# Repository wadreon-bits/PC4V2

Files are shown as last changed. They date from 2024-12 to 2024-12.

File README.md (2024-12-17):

# PC4V2  Proto Controller 4volt 2 Channel (Another Stupid Acronym) 

Prototype test platform- Code application and devkit based hardware.
DC Motor controller with Display UI, Aimed to test small ~4volt ERM motors. 2 motor output channels.
Capable of providing 10bit waveform on 2 motor drive h-bridge channels at 100Hz update rate. 

Repository Directory: (protocontrol_4V2)
- ArrayBuilding_Excel 	- Method to build waveforms with excel. Ask for demo.
- Control_Enclosure_R1 	- MCADD files for device enclosure
- PC4V2_Prog1		- Arduino Sketch Folder
- ProtoCheatSheet.doc	- Quick Device instructions
- README.md		- .GIT repo readme doc

Using The Assembled Device:
1. Charge for approx 1hour if discharged -uUSB. Fully charged should read around 4.15vdc or more when device unplugged. 
2. Press either button to wake device
3. Press UP/DWN to select mode#(User setting? Level? Idk)
4. Set to mode#0 to turn device off- will resume sleep in a few seconds.
5. As shipped-The modes are programmed as follows
	- #1-3 are constant speed, 50%, 75%, 100%(motors a/b opp directions)
	- #4-10 are various on/off, and sweeping patterns. Easy to mod. 
	- Can read mode_arrays.h within the code to get a better idea of the patterns programmed. Easy to mod.
6. Alternative hidden mode- Press and hold both buttons simultaneously for >1sec to enter/leave the direct motor drive mode.
	- Use Up/Dwn buttons to set the desired %power to both motor channels. 0%=OFF 100%=ON   
	- NOTE! Most ERM motors will NOT start spinning until >15-20% power is applied. Mode starts at 0.0%.
	- It will stay awake in this mode. Press both btns >1sec again to return to user mode.

Setting Up Arduino IDE: (Updated after R2.2 - after RyanR first load)
1. Download latest IDE from Arduino. Built using (version 2.3.3)
2. In order to add Adafruit framework- perform following
 - File>>Preferences  towards bttm-
 - Copy the following link into 'Additional boards managers URLs:
 - https://adafruit.github.io/arduino-board-index/package_adafruit_index.json
3. IDE Left pane >> BOARDS MANAGER>> Search for Adafruit SAMD
 - Install the SAMD package that includes the FeatherM0 Express
4. Using IDE library Manager - Search for & Install the following libraries
	- Adafruit_NeoPixel
	- Adafruit_SSD1306
	- Adafruit_GFX
	- ArduinoLowPower
6. Lastly - Move the 'PC4V2_Prog1' folder into your Arduino Sketch folder--> Documents>Arduino. 
 - Depending on windows setup- Documents might be a few places - Check onedrive
 - Can check in IDE-  File>>Preferences>>Sketchbook Location: 
7. Tool chain is setup and ready to use. Can edit, compile, and flash devices 

Programming Device:
1. Plug into PC USB port
2. Open Arduino IDE
3. Tools>>Boards  - Select Adafruit Feather M0 Express
4. With a Tack or Paperclip-  Double click the pinhole button on the front button face- proto_UIcontrol. 
5. After the double-click, the feather should re-mount as a new USB com-port. 
	- Helpful note- The Board LED will slowly pulse Red when in proper bootloader mode. Board LED Can been seen right next to feather USB port. 
6. Tools>>Port  - Select the port that now shows (Adafruit Feather M0 Express (SAMD21)).
7. Sketch>>Upload.  The IDE will begin compiling, then begin flash programming the device. 
8. Programming should complete with no warnings or errors. 

The Hardware consists of the following:
1. Feather M0 Express w/Stacking headers
2. Feather OLED 128x32 with standard male header
3. 350mAH lipo - Adafruit- Fits between stacked feather boards. 
4. DRV8833 TI Drive Breakout
5. 3d Printed housing - Onshape: Proto_UIcontrol>>Enclosure4V2
6. See code for pinouts 
7. (Not Used)BS84 P-Chan Mosfet- OLED Pwr Switch
8. (Not USed)0402 15-20k ohm resistor (Pull up for pchannel)

Firmware Notes:
1. Firmware application built original in AS7 at LDC- modified to use Arduino framework
for this version. Based on PC4V1. Now named PC4V2
2. Git Repo will hold updated firmware application files. Along with support docs and support tools.
3. This is DEMO firmware only. No attempts to optimize have been made. All open source. 

FW Functional Description:
1. This application bascially updates a 10bit PWM value every 10milliseconds
   for two h-brige motor outputs. These values come from pre-defined arrays in mode_arrays.h
2. The app scans for valid button presses, and update the current mode_variables
3. If new information is avaialable- an update is made to the OLED 

Modifying Motor Waveform Patterns: 
Adjustments to ERM output patterns will be made within mode_arrays.h
This file can easily be modified for any waveform of interest.
Code must be re-compiled after changes are mode.  

Each mode has 2 arrays, 1 for each motor channel A/B.  

These simple integer arrays hold 10bit PWM duty cycle values.
These values are processed at 100Hz. Array can be length 1 to MANY! Limited by prog flash space.
Values can be between 0(motor off), and 1023(Motor full pwer). Negative Values reverse motor
direction. DO NOT QUICKLY REVERSE MOTOR DIRECTION WITHOUT SLOWING TO A STOP FIRST. 
 
REVERSE DIR	OFF	FORWARD DIR
  -1023		0	1023

const int ExampArrayA[] = {1023} 		//Motor A forward dir 100% power
const int ExampArrayB[] = {0, -511, 0, -511}	//Motor B reverse dir staccato 50% power

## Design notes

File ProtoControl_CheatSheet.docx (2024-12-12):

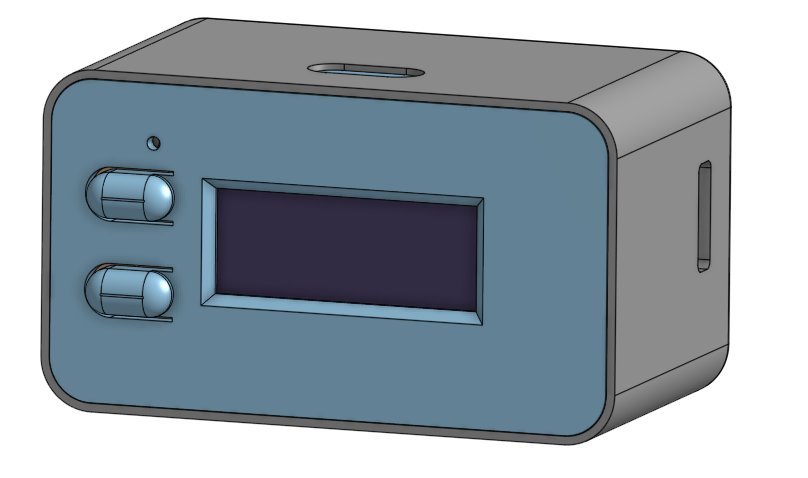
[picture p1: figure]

Screw-Post to Connect

2 Motors

UP+DOWN Buttons

uUSB Charging Port

OLED Display

Charging:

1. Use standard micro-USB cable to charge battery. Charging will take approx. 1hour.
2. Battery icon will read full- and the pack voltage should be around ~4.15Vdc when charged

How To Use:

1. Press ANY button to wake device up
2. Press Up/Dwn Button to set to desired mode #1-10
3. Set to Mode #0 to turn off device. Will resume sleep in a few seconds

How To Modify Motor Waveforms OR Reprogram Device – See Github repo readme

https://github.com/wadreon-bits/ProtoControl_4V2

How To Wire Motors

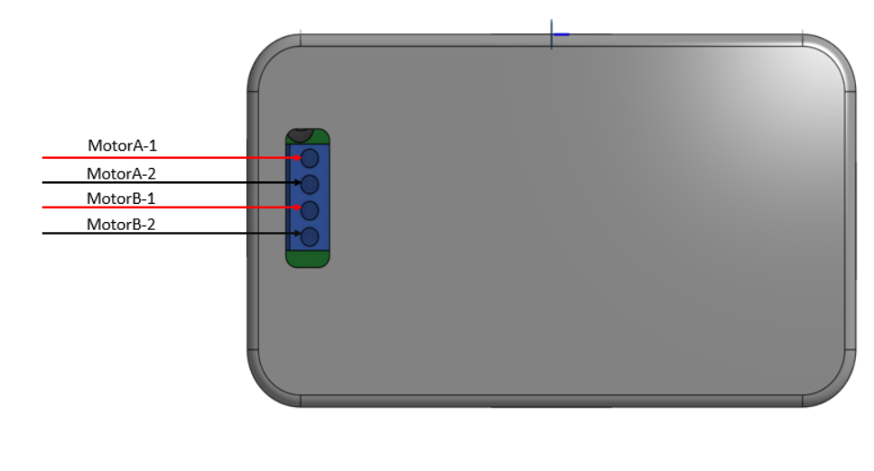
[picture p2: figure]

Proto Controller 4volt 2 Channel 120524

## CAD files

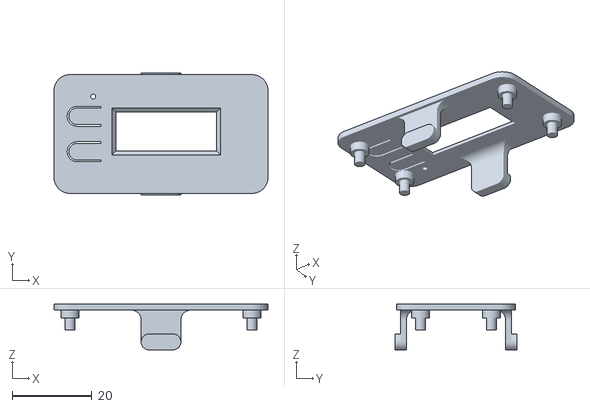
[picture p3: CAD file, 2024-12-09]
Control_Enclosure_R10/Enclosure4V2_R10 - Front.stl
53.8 x 30.6 x 11.5

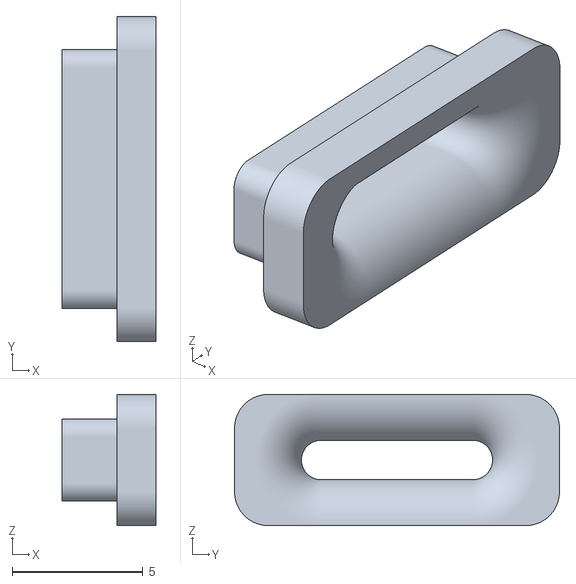
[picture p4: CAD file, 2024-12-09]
Control_Enclosure_R10/Enclosure4V2_R10 - Strain_Relief.stl
3.60 x 12.4 x 5.01

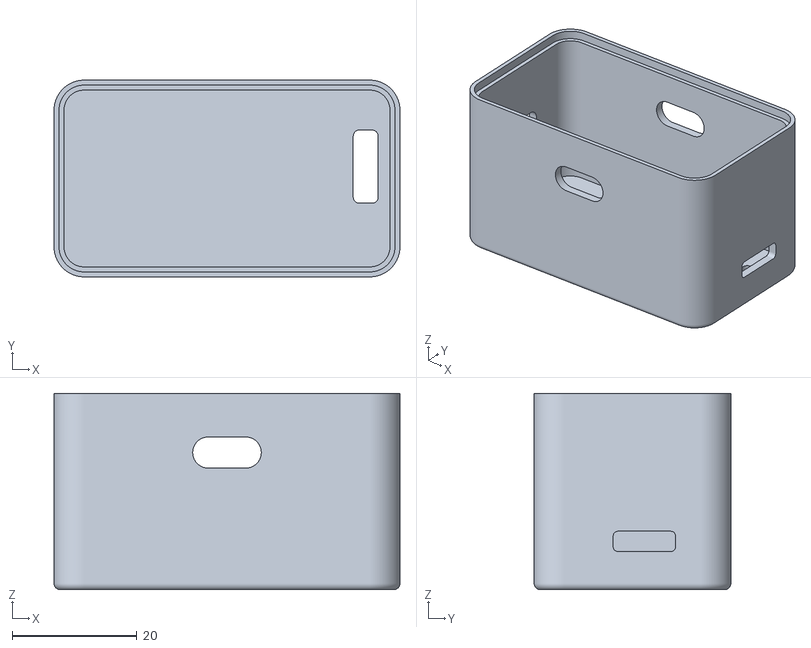
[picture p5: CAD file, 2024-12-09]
Control_Enclosure_R10/Enclosure4V2_R10 - Back.stl
55.5 x 31.6 x 31.5

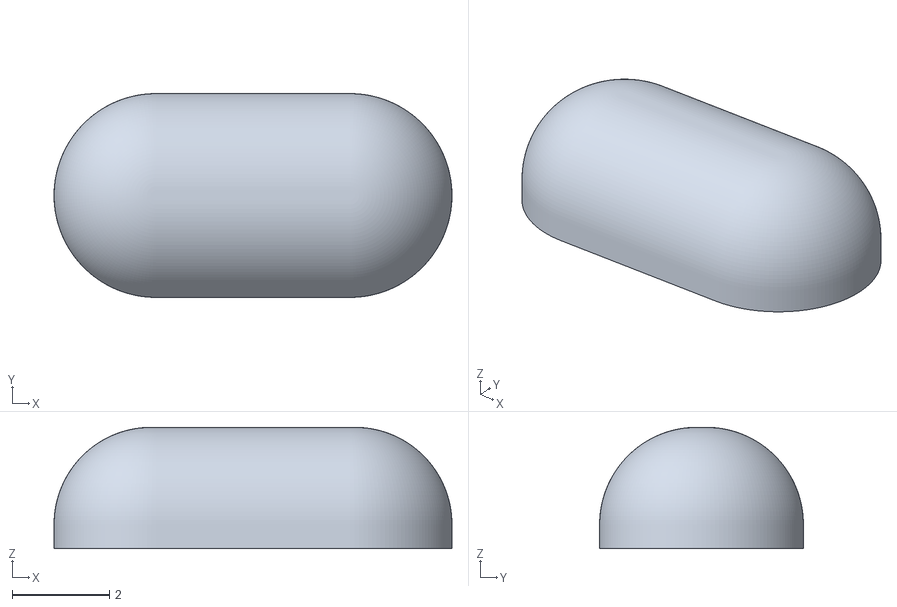
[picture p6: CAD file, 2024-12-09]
Control_Enclosure_R10/Enclosure4V2_R10 - Btn_Oval.stl
8.20 x 4.20 x 2.50

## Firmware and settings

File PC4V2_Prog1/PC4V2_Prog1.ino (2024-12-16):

/*
111824
PC4v2 - MotorTester1S 
Proto Control 4Volts Dual HBridge 2 channel output

FW Versions: See Repo for version history
1.0		111824		Working rebuild of PC4V1 built for LDC. Refactored code for Arduino Framework. Sequences array pwm data to 2 H-bridge channels. 

Arduino Setup Notes: 
See pc4v_support.h for all the libraries needed. Must follow adafruit instructions on installing their libraries. Such as GFX etc.
- Adafruit libraries are all located on a github repo. New version of arduino IDE can search and install adafruit libs natively.
- So if using >=Arduino Version 2.3.3, No need to add link for the adafruit git repo's. 
Sketch >> Include Library >> Library Manager >> Manage Libraries >> Search for library 

HARDWARE NOTES:
Devkit Based Hardware- 
FeatherM0Express
FeatherOLED
DRV8833 Breakout

SOME BUTTON DEFINITIONS - REMOVE NO LONGER NEEDED FOR BASIC UI 
UP - Generic Up index for UI
DWN - Generic Dwn index for UI

Primary Functions to Adjust for Product Interface -
	- app_update()    App Timing			      Manages	primary application timing/time slicing. Basic app. 
	- btn_scan()      BTN UI/Ergonomics			Manages Button ergo- press timing, clicks, etc. Removed clicks for ERM PC4V2
	- mode_manager()	Functional Modes		  Manages enabling motor/led modes and handling periodic mode events. Processes mode_arrays!
  - disp_manager()  OLED Interface        Single function to write/read from OLED display. 
	
Notes-
Arduino makes code writing FAST!!! I hate the IDE- USE AS7 or VScode 
*/
//##############################################################
//  Preamble Include definitions
//##############################################################

#include "pc4v_support.h"

//##############################################################
//  FUNCTION PROTOTYPES
//##############################################################
/*
// Proper .C - populate Function proto's. For compiling with standard C compiler 
// DELETED - ARDUINO FRAMEWORK DOE SALL THIS
*/
#if SOFTWARE_SERIAL_AVAILABLE
  #include <SoftwareSerial.h>
#endif
//End of Auto generated function prototypes by Atmel Studio

/*MACROS*/  
#define WIRE Wire 
#define arrayLen(x) sizeof(x)/sizeof(x[0])  //custom macro for sizing motor/led arrays. 
//#define arrayLen(x) sizeof(x)/sizeof(x[0])  //custom macro for sizing motor/led arrays. 

/*GLOBAL APP EVENT FLAGS*/ 
volatile bool flag_scanBtns   = false;    //flag
volatile bool flag_10ms       = false;    //flag
volatile bool flag_100ms      = false;    //flag
volatile bool flag_1second    = false;    //flag

volatile bool flag_flickerLED = false;    //event
volatile bool flag_gotoSleep  = false;    //event
volatile bool flag_wake_init  = false;    //flag
volatile bool flag_crit_batt  = false;    //flag
volatile bool flag_low_batt   = false;    //event
volatile bool flag_updateDisp = false;    //event

//volatile bool uiflag_fastRate = true; 
volatile bool flag_blockSleep = false;    //set to true to disable sleep 
volatile bool disp_changed    = false; 
bool written_once             = false;


/*Global variables*/
volatile unsigned int btns_state  = 0;	// read - stores pins states
volatile unsigned int btns_cnt    = 0;	// stores pins states
unsigned int btns_stateLast       = 0;		// last pin states


volatile signed int drive_state   = 0;	// Read - Current output duty of drive. 
volatile signed int req_mode      = 0;	// 
volatile signed int active_mode   = 99;	// MODE = USER SETTING or USER LEVEL
volatile signed int aux_pwm       = 0; 
unsigned int led_on               = 0;				// counter to turn off led
unsigned int sleep_counter        = 0;         //
int timer_id                      = 0; 
unsigned int bod33_cnt            = 0; 

int temp_32; 

float batt_volts;
float avg_batt_volts = 4.0; 
String batt_soc; 
//dispState_e disp_state = BOOT; 
enum appState_e app_state = BOOT; 

/* Instantiate Class Object Variables */
Timer app_timer;
Adafruit_NeoPixel serled(1, SER_LED, NEO_GRB + NEO_KHZ800);
#ifdef OLED_CONNECTED
  //Adafruit_SSD1306 display = Adafruit_SSD1306();
  Adafruit_SSD1306 display = Adafruit_SSD1306(128, 32, &WIRE);
#endif


// Synch AC
static __inline__ void ACsync() __attribute__((always_inline, unused));
static void   ACsync() {
	while (AC->STATUSB.bit.SYNCBUSY == 1);
}
// Synch GCLK
static __inline__ void syncADC() __attribute__((always_inline, unused));
static void syncGCLK() {
	while (GCLK->STATUS.bit.SYNCBUSY == 1);
}

//this will be called when the BOD33 threshold is crossed
//once the controller comes out of reset (VAnna rises above threshold)
// so when the battery gets toward BOD33, it will begin interuppting the
//void PM_Handler(){
		//
//}
void SYSCTRL_Handler(){   //BROWN OUT DETECTED 
	int temp_32;

	SYSCTRL->INTFLAG.bit.BOD33DET = 0x1; // clear flag to re-arm interrupt
	SYSCTRL->INTENCLR.bit.BOD33DET = 0x1; //disable interrupt
	//serled.setPixelColor(0, serled.Color(150, 0, 0));
	//serled.show();
	REG_SYSCTRL_INTFLAG |= 0x00000400;  //clear the interrupt flag
	flag_crit_batt = true;
}

/*Power Manager interupt support routine - Not being used*/
//void PM_handler(void){
	//if(REG_PM_RCAUSE == 0x04){ //Brown Out Detected-- Goto Sleep
		//app_timer.stop(timer_id);
	//}
//}

// the setup function runs once when you press reset or power the board
void setup() {
  /* Disable the brown-out detector during configuration,
    otherwise it might misbehave and reset the
    microcontroller. */
  SYSCTRL->BOD33.bit.ENABLE = 0;
  while (!SYSCTRL->PCLKSR.bit.B33SRDY) {};  //wait for sync

  /* Configure the brown-out detector so that the
    program can use it to watch the power supply
    voltage */
  SYSCTRL->BOD33.reg = (
  /* This sets the minimum voltage level to 3.0v - 3.2v.
      See datasheet table 37-21. */
  SYSCTRL_BOD33_LEVEL(48) |
  /* Since the program is waiting for the voltage to rise,
      don't reset the microcontroller if the voltage is too
      low. */
  SYSCTRL_BOD33_ACTION_INTERRUPT|
  
  /* Enable hysteresis to better deal with noisy power
      supplies and voltage transients. */
  SYSCTRL_BOD33_HYST);

  /* Enable the brown-out detector and then wait for
     the voltage level to settle. */
  SYSCTRL->BOD33.bit.ENABLE = 1;        

  SYSCTRL->INTENSET.bit.BOD33DET = 0x1; //enable BOD33 interrupt 
	
	NVIC_EnableIRQ(SYSCTRL_IRQn);   //enable global interupts
  // //END NEW BOD CODE HERE
	//REG_SYSCTRL_INTENSET |= 0x00000400; //enable BOD33 interrupt; 
	SYSCTRL->INTFLAG.bit.BOD33DET = 0x1;    //Enable BOD interrupt
	
	pinMode(13, OUTPUT);                //Board Simple RED LED
  pinMode(OLED_EN_PIN, OUTPUT);       //OLED Enable - Not used in current vers
  digitalWrite(OLED_EN_PIN, LOW);     //TURN ON DISPLAY EN
  pinMode(DRIVE_FLT_PIN, INPUT);      //FAULT I/O from motor drive PULLUP??
  pinMode(DRIVE_SLP_PIN, OUTPUT);     //Sleep I/O from motor drive
  digitalWrite(DRIVE_SLP_PIN, HIGH);  //TURN ON DRIVE 
  
	delay(200);                       //wait for OLED charge pumps etc
  pinMode(DRIVE_A1_PIN, OUTPUT);    //Drive A1 Output PWM PIn
 	pinMode(DRIVE_A2_PIN, OUTPUT);    //Drive A2 Output PWM PIn
  pinMode(DRIVE_B1_PIN, OUTPUT);    //Drive B1 Output PWM PIn 
	pinMode(DRIVE_B2_PIN, OUTPUT);    //Drive B2 Output PWM PIn
	
  pinMode(BTN_1_PIN, INPUT_PULLUP); //OLED Button - Not using Middle Button
	pinMode(BTN_2_PIN, INPUT_PULLUP); //OLED Button - Not using Middle Button

	set_drive(1,0);                   //Turn Off Drive Channel A
  set_drive(2,0);                   //Turn Off Drive Channel A
#ifdef DEBUG_PRINTS
	Serial.begin(115200);             //If Debug Defined- Console Prints
  //while(!Serial);
#endif
	analogWriteResolution(10);        //Increase Analog Write Res for PWM channels
  analogReadResolution(12);         //Increase Analog Read Res for Batt Measure and future motor measure
	serled.begin();                   //Init serial Pixel 
	serled.clear();                   //Set pixel to off
	serled.show();                    //send off command to pix
 #ifdef OLED_CONNECTED
    display.begin(SSD1306_SWITCHCAPVCC, 0x3C);  // initialize with the I2C addr 0x3C (for the 128x32)
    app_state = BOOT;
    manage_disp();                          // Display BOOT screen - version etc. 
#endif

#ifdef DEBUG_PRINTS
    Serial.print(F("FW Version:")); //Console version print
	  Serial.println(F(FW_VERSION));   
#endif 
    delay(2000);                    //Just wait for everything
  //write version;
	timer_id = app_timer.every(APP_BASE_TIME, app_update);  //Main app timer
	__enable_irq(); //enable global IRQ;                    //Enable Global Interuppts- Not sure if needed in arduino land
	flag_gotoSleep = true;            // Goto sleep right away
  app_state = USERMODE; 
  flag_updateDisp = true;           // 
}


/*Initialize things before Sleep*/
void init_sleep(void){ //called before sleep call
  //DRIVE OFF
  set_drive(1, 0);                //TURN OFF MOTOR1
  set_drive(2, 0);                //TURN OFF MOTOR2
  //delayMicroseconds(20);
  //Set Sleep Pin
  pinMode(DRIVE_SLP_PIN, OUTPUT); 
  digitalWrite(DRIVE_SLP_PIN, LOW);
  pinMode(DRIVE_SLP_PIN, INPUT);

  //LEDS OFF
  pinMode(BRD_LED, OUTPUT);   //
  digitalWrite(BRD_LED, LOW); //TURN OFF FRAMEWORK LED
  serLed_off();               //TURN OFF SERIAL LED
  
  //SETUP WAKE BTNS
  pinMode(BTN_1_PIN, INPUT_PULLUP);
	pinMode(BTN_2_PIN, INPUT_PULLUP);

  //CLEAR AND DISABLE DISPLAY 
  app_state = INITSLEEP; 
  manage_disp();
  delay(1);
  //DISABLE DISPLAY
  pinMode(OLED_EN_PIN, INPUT);  //PULL UP TURNS OFF

  //SETUP WAKE INTERUP 
  LowPower.attachInterruptWakeup(BTN_1_PIN, wake_ISR, FALLING);
	LowPower.attachInterruptWakeup(BTN_2_PIN, wake_ISR, FALLING);
  //__enable_irq();
}

/*Initialize things after Wakup*/
void init_wakeUp(void){ //called right after wakeup
  
	SYSCTRL->INTENSET.bit.BOD33DET = 0x1; //enable BOD33
	NVIC_EnableIRQ(SYSCTRL_IRQn);
	//REG_SYSCTRL_INTENSET |= 0x00000400; //enable BOD33 interrupt;
	SYSCTRL->INTFLAG.bit.BOD33DET = 0x1; //clear flag to re-arm interrupt

  //ENABLE DRIVE
  pinMode(DRIVE_SLP_PIN, OUTPUT);
  digitalWrite(DRIVE_SLP_PIN, HIGH);
  
  //ENABLE DISPLAY
  pinMode(OLED_EN_PIN, OUTPUT);
  digitalWrite(OLED_EN_PIN, LOW);  //set low to enable - pchannel hi-side fet. 

  delay(200); //allow charge pump to fill on OLED- Takes awhile
  app_state = INITWAKE; 
   
  manage_disp();
  app_state = USERMODE;
  //manage_disp(INITWAKE);
  //__enable_irq();   //re-enable global interrupts
}

/*Button Interrupt- Can use. Or rely on app polling*/
// void btn_ISR() {
//   flag_scanBtns = true;
// }
/*Wake Interrupt- Called for wakeup ISR */
void wake_ISR(){
  //__disable_irq();
	sleep_counter = 0; 
  flag_wake_init = true; 
	//bod33_cnt = 0; 
}

/*Application Timing*/
void app_update() { //runs every 10ms
  volatile static int btnScan_timer;
  volatile static int tenms_timer, hundredms_timer, oneSecond_timer;

  /*Used to Scope Timer functions- Can bury within timeslice loops-10ms,100ms,1s etc. */
  #ifdef ENABLE_TIMERSCOPE
    pinMode(BRD_LED, OUTPUT);
    digitalWrite(BRD_LED, LOW);
    pinMode(BRD_LED, INPUT_PULLUP);
  #endif

  /*Polling Button Flag */
  if (++btnScan_timer >= BTN_SCAN_PER) { //BTN_SCAN_PER = 2 so 20millisconds 50hz
    btnScan_timer = 0;
    flag_scanBtns = true;
  }

  if (tenms_timer == TEN_MS_PER) {
    tenms_timer = 1;
    flag_10ms = true;

    if (hundredms_timer == (TEN_MS_PER * 10)) {
      hundredms_timer = 1;
      flag_100ms = true;
      if (oneSecond_timer == (TEN_MS_PER * 10)) {
        flag_1second = true;
        oneSecond_timer = 1;
      }
      else
        oneSecond_timer++;
    }
    else
      hundredms_timer++;
  }
  else
    tenms_timer++;
}//end of function

/*simple btn scan function - loads byte with pin status- Reads buttons/Debounces/Manages state variables*/
unsigned int scan_btns() { //ENTER FUNCTION CALL PERIOD HERE: 20ms
  static unsigned int case_cnt;
  static unsigned int ui_static_cnt = 0;
  static unsigned int btn_release_event = 0;
  static bool ui_blocked = false;

	pinMode(BTN_1_PIN, INPUT_PULLUP);
	pinMode(BTN_2_PIN, INPUT_PULLUP);
  delayMicroseconds(20);
  //btns_state will be a byte holding multiple switch states 
  // for PCV4 = 2btns.  0|0|0|0|0|0|BTN2=UP|BTN1=DWN
  btns_state = ((int(!digitalRead(BTN_UP) << 1)) | (int(!digitalRead(BTN_DWN)))  );
  //int btn_state[2]   btn_state[1]: btn pressed, btn_state[2]: count

  /*TEST FOR BTNS CHANGED??*/
  if (btns_state != btns_stateLast) {   // ### TEST FOR CHANGE IN BTNS ###
    btns_cnt = 0; 
    case_cnt = 0; //btns have changed- reset case_cnt
    if (btns_state == 0){  //btns have changed, and are just released released 
      if(btn_release_event) btns_state = btn_release_event;
      btn_release_event = 0;
    } 
  }
  else    //!### NOTHING HAS CHANGED !###
    btns_cnt++;               //counting any press combo, case_cnt counts only defined cases. 
  
  /* TEST FOR BUTTONS PRESSED OR RELEASED */
  if (btns_state == 0) {
    ui_static_cnt++;
    ui_blocked = false;
  }
  else{
    ui_static_cnt = 0;
    sleep_counter = 0;
    //btns_state = btns_state<<app_state; 
  }

  /*SAVE BUTTON STATE*/
  btns_stateLast = btns_state; //maybe move to end. Incorporate single click pending test up top of function
  

  if(ui_blocked) return btns_state;

  switch (btns_state) {   //Begin Case Statement User Interface - UI 
    case 0:
      case_cnt = 0;
    break;

    case BTN_UP_MASK:
      /*Begin testing for short First Click*/
      if (case_cnt == BTN_SHORTPRESS_TIME) {
      //case_cnt = 0;
        req_mode++; 
      }
      case_cnt++;  //case_cnt is an integer will rollover at 65k- Can play with location to make one-shot or repeated events
      if(case_cnt >= 10)
        case_cnt = 0; 
    break;

    case BTN_DWN_MASK:
      if (case_cnt == BTN_SHORTPRESS_TIME){
        req_mode--;
        //ui_blocked = true; 
        //case_cnt = 0; //reset case_cnt for sustained increment
      }      
      case_cnt++;
      if(case_cnt >= 10)
        case_cnt = 0; 
    break;

    case BTN_ALL_MASK:
      if (case_cnt == BTN_LONGPRESS_TIME) {
        //case_cnt = 0;
        if(app_state == USERMODE){
          app_state = AUX;
          serLed_on(197, 42, 121);
        }
        else if(app_state == AUX){
          app_state = USERMODE;
          serLed_off();
        }
      }
      flag_updateDisp = true; 
      case_cnt++;
      req_mode = 0; 
    break;

    default:
      case_cnt = 0;
      break;

  }//end switch(btns_state)

  return btns_state;
}//end scan_btns function

/*Handles Timer UI Events for USER or AUX modes*/
void manage_uiEvents(){  //change to manage_uiEvents(); 
  //static enum appState_e app_state_last; 
  switch(app_state){
    case USERMODE:
      usermode_events();
    break;

    case AUX:
      aux_events();
    break;

    default:
    break;
  }//end of switch
}//end of function


/*Handles Aux Timer Event UI cmnds*/
void aux_events(){

    sleep_counter = 0; //keep awake in aux mode

    if(req_mode>204)  req_mode = 0;
    if(req_mode<0) req_mode = 0;

    aux_pwm = req_mode * 5; 
    if(drive_state != aux_pwm){
      set_drive(1, aux_pwm);
      set_drive(2, aux_pwm);
      flag_updateDisp = true; 
      active_mode = req_mode;  
    }
  
}
/*Manage Drive and LED - run every mode time slice = 10ms */
/* Should take time to make this a seperate class- for reuse: All cases same*/
void usermode_events(){
	static int case_cnt = 0;
	static int period_cnt = 0; 
	static int mode_indexA = 0;	//generic use motor channelA
	static int mode_indexB = 0;	//generic use motor channelB
  static unsigned int arraysizeA = 0;
  static unsigned int arraysizeB = 0;
  int offset = req_mode -1;

  if(req_mode > 10)
    req_mode = 0;
  if(req_mode < 0)
    req_mode = 0;

  if(req_mode != 0) sleep_counter = 0; //keep awake if not idle

	if(req_mode!=active_mode){
		mode_indexA=0;
		mode_indexB=0;
    flag_updateDisp = true; 
    #ifdef DEBUG_PRINTS
      Serial.println("Mode:"+String(req_mode));
    #endif
	} 

	switch(req_mode){
		case 0:
			//Idle ready for input or sleep timeout
			if(drive_state!=0){
				set_drive(1, 0);
        set_drive(2, 0);
      }
			serLed_on(serLed_idleArray[period_cnt][0], serLed_idleArray[period_cnt][1], serLed_idleArray[period_cnt][2]);
			period_cnt++;
			if(period_cnt>(arrayLen(serLed_idleArray)-1))
				period_cnt = 0; 
			if(active_mode!=req_mode)
				active_mode = req_mode; 
			break;
		
		case 1 ... 10:
			if(active_mode!=req_mode){//mode_counters should be zero
        set_drive(1, 0);
        set_drive(2, 0);
				serLed_on(usermode_leds[offset][0],usermode_leds[offset][1],usermode_leds[offset][2]); //rgb value, 
        
        set_drive(1, ptr_arraysA[offset][0]);        //set drive in motion using first value in array
        set_drive(2, ptr_arraysB[offset][0]);        //set drive in motion using first value in array
        active_mode = req_mode;
			}
      else{
        if(arrayA_lengths[offset]>1){                                     //if array is larger than 1, continue indexing
          set_drive(1, ptr_arraysA[offset][mode_indexA++]);
          if(mode_indexA>(arrayA_lengths[offset]-1))
            mode_indexA = 0;

        }
        if(arrayB_lengths[offset]>1){
          set_drive(2, ptr_arraysB[offset][mode_indexB++]);
          if(mode_indexB>(arrayB_lengths[offset]-1))
            mode_indexB = 0;
        }
      }   
			break;
	} // end of switch
}
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
void loop() {

  app_timer.update();

  if(flag_wake_init){
    flag_wake_init = false; 
    init_wakeUp();
    app_state = USERMODE; 
  }
    
  if(flag_gotoSleep){
	  if(!flag_blockSleep){
		  flag_gotoSleep = false;
		  flag_crit_batt = false;
      written_once = false; 
		  init_sleep();
		  //NVIC_SystemReset();
		  LowPower.deepSleep();
	  }
  }
 
  if(flag_low_batt){
    flag_low_batt = false; //remove if sleep required to clear?? 
    app_state = LOWBATT; 
    flag_updateDisp = true; 
  }

  if(flag_flickerLED){
	  if(led_on == 0){
			serLed_off(); 
	  }
	  else
		led_on--; 
  }
  
  if (flag_scanBtns) {
    flag_scanBtns = false;
    scan_btns();
  }

  if (flag_10ms) {
    flag_10ms = false;

    if(flag_crit_batt){               //move to event manager? 
      flag_crit_batt = false;
      sleep_counter == (SLEEP_TIMEOUT-2);
        serLed_on(120, 0, 0); //low batt red 
    }
    else
      manage_uiEvents(); //manage_uiEvents();
  }//end of 10ms

  if (flag_100ms) {
    flag_100ms = false;
    manage_disp();
    if(btns_state == 0)
      read_batt();
  }//end of 100ms

  if (flag_1second) {
    flag_1second = false;

		if(sleep_counter == SLEEP_TIMEOUT) 	//move to moode_manager case0???
			flag_gotoSleep = true;
		else
			sleep_counter++;
  }//end of 1second
 
} //END OF MAIN() // ARDUINO LOOP() 




//BELOW CONVENIENCE FUNCTIONS


/*Primary H-Bridge Motor Function*/ //setdrive(channel, duty))
void set_drive(int channel, int duty){ //(-1023 to 1023, 0 is off)
	int temp_pinA, temp_pinB; uint8_t pwm_channel; 

  if(channel == 1){
    temp_pinA = DRIVE_A1_PIN;
    temp_pinB = DRIVE_A2_PIN;
    //pwm_channel = A0; 
    //driveA_state = duty;
  }
  else if(channel == 2){
    temp_pinA = DRIVE_B1_PIN;
    temp_pinB = DRIVE_B2_PIN;   
    //pwm_channel = A1; 
    //driveB_state = duty;
  }
  else
    return; 

  pinMode(temp_pinA, OUTPUT);
  pinMode(temp_pinB, OUTPUT);
  //pinMode(pwm_channel, OUTPUT);
  
  if (duty != 0){
		if (duty > 1023)
		duty = 1023;
		if (duty < -1023)
		duty = -1023;
		
		if(duty>0){ //dir1
			digitalWrite(temp_pinA, HIGH);
			digitalWrite(temp_pinB, LOW);			
			analogWrite(temp_pinB, (1023-duty));
		}
		else if(duty<0){//dir2
			digitalWrite(temp_pinA, LOW);
			digitalWrite(temp_pinB, HIGH);
			analogWrite(temp_pinA, abs(1023+duty));
		}
		
		drive_state = duty;
	}
	else{ //duty = 0 - Turn off motor. 
		pinMode(temp_pinA, OUTPUT);
		pinMode(temp_pinB, OUTPUT);
		digitalWrite(temp_pinA, LOW);
		digitalWrite(temp_pinB, LOW);
		drive_state = 0; //OFF
	}
	//duty_last = duty;
}

/*Reads and averages battery measurement */
void read_batt(void){
  float temp_avg = 0;
  //static float avg_buffr[10];
  static float avg_buffr[10] = {4.0, 4.0, 4.0, 4.0, 4.0, 4.0, 4.0, 4.0, 4.0, 4.0};
	static int i = 0; 

 // if(btns_state != 0) return; 

	pinMode(BTN_UP, OUTPUT);
  digitalWrite(BTN_UP, HIGH);
  pinMode(BTN_UP, INPUT);
	//delayMicroseconds(100);
	delay(2);
	float measuredvbat = analogRead(A7);
	//float measuredvbat = 3.3; 
	measuredvbat *= 2;    // we divided by 2, so multiply back
	measuredvbat *= 3.3;  // Multiply by 3.3V, our reference voltage
	measuredvbat /= 4096; // convert to voltage

	batt_volts = measuredvbat; 
  avg_buffr[i] = batt_volts;
  i++;
  if(i >= 10)
    i = 0;
  
  for(int j=0; j<=9; j++){
      temp_avg += avg_buffr[j];
  }
  temp_avg = temp_avg/10;

  if(abs(avg_batt_volts-temp_avg)>=0.05)
    flag_updateDisp = true;
  // if(avg_batt_volts != temp_avg)
  //   flag_updateDisp = true;

  avg_batt_volts = temp_avg;

  if(avg_batt_volts <= APP_LVC)
    flag_low_batt = true; 

  #ifdef DEBUG_PRINTS
    Serial.println(i);
    Serial.println(batt_volts); 
    Serial.println(avg_batt_volts); 
  #endif
  //average the voltage
}


/*Toggles Board LED - No BRD LED available on PC4V1*/
void toggle_brdled(bool en) {		//simple LED on pin 2 
  static bool state;

  if (en) {
    pinMode(BRD_LED, OUTPUT);
    digitalWrite(BRD_LED, state);
    state = !state;
  }
  else
    pinMode(BRD_LED, INPUT);
}

/*Shift Register LED driver*/
void serLed_on(int valr, int valg, int valb){
	serled.setPixelColor(0, serled.Color(valr, valg, valb));
	serled.show();
}

/*Shift Register LED Overide OFF*/
void serLed_off(void){
	serled.clear();
	serled.show();
	flag_flickerLED=false;
	led_on = 0;
	
}

/*Shift Register LED Simple Flicker Function*/
void serLed_flicker(unsigned int dur){
	serled.setPixelColor(0, serled.Color(0, 150, 150));
	serled.show();
	flag_flickerLED=true;
	led_on = dur; 
}

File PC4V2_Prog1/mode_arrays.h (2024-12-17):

#ifndef mode_array_h
#define mode_array_h

#include <WString.h>
#define arrayLen(x) sizeof(x)/sizeof(x[0])  //custom macro for sizing motor/led arrays. 
/*
Drive and LED Arrays are processed as follows- 
	EACH ROW ELEMENT IS PROCESSED PER MODE_MANANGER EVENT = Every 10ms
	So Each 100 array elements will provide 1second of motor waveform/pattern
  100HZ processing. So up to a 100Hz 'Pattern' can be modulated   DIRB-100%     MOTOR OFF   DIRA-100%
  Each array position holds a 10bit motor output pwm value.         -1023   ~~~~  0 ~~~~~    +1023.
  Negative values turn the motor in the reverse direction. Do not reverse motor quickly!!
  ex: const unsigned int DemoArray[] = {1023, 1023, 0, 0};  This array makes motor goto full power for 20ms, then Off for 20ms, repeat. 
  Many methods to visualize and simplify building the waveform pattern
  Use Python script- ExceltoCArray.py to simplify generating large arrays. 
  Excel- Build pattern, equation, graph etc.  Can export simple .CSV data. Simple! 
  Or just hand build arrays below. 
  no immediate limit to array lengths. Limited by Flash memory- Constants store in Flash. 

  NOTE- as of 11/27/24-  In order to handle a second motor channel. Also have ability to have motorsA/B have different patterns,
  I just added 2 arrays for each mode A/B arrays. They can be completely different values and length. 
  driveA = Drive Channel A
  driveB = Drive Channel B  
  
  **!! DO NOT RECOMMEND QUICKLY REVERSING A MOTORS ROTATION DIR!!! No FW/HW protection built in. 
  Stop motor before reversal- exact timing specific to motor. 
*/

//######################### MODE 1 ARRAY ############################################//     Single DC Output Value (0 to +/-1023) = (0-100% Power), negative changes motor dir
const int driveA_mode1[]  = {900};    //Motor Channel A
const int driveB_mode1[]  = {900};    //Motor Channel B

//######################### MODE 2 ARRAY ############################################//     Single DC Output Value (-1023 <-> +1023) = (0-100% Power), negative changes motor dir
const int driveA_mode2[]   = {770};
const int driveB_mode2[]   = {770};

//######################### MODE 3 ARRAY ############################################//     Single DC Output Value (-1023 <-> +1023) = (0-100% Power), negative changes motor dir
const int driveA_mode3[]   = {1023};    //showing motors going opposite dir
const int driveB_mode3[]   = {-1023};   //showing motos going opposite dir

//######################### MODE 4 ARRAY ############################################//     10Hz Square Wave alternating ~50%/~100%
const int driveA_mode4[]   = {500, 500, 500, 500, 500, 1000, 1000, 1000, 1000, 1000};  
const int driveB_mode4[]   = {500, 500, 500, 500, 500, 1000, 1000, 1000, 1000, 1000};  

//######################### MODE 5 ARRAY ############################################//     20Hz Square Wave Alternating 0%/~100%
const int driveA_mode5[]   = {0, 0, 0, 0, 1000, 1000, 1000, 1000}; 
const int driveB_mode5[]   = {0, 0, 0, 0, 1000, 1000, 1000, 1000};  

//######################### MODE 6 ARRAY ############################################//     50Hz Square Wave ~75% power
const int driveA_mode6[]  = {820,0,820,0,820,0,820,0,820,0};                          //showing different array values per motor array
const int driveB_mode6[]  = {0,820,0,820,0,820,0,820,0,820};

//######################### MODE 7 ARRAY ############################################//     Whatever pattern
const int driveA_mode7[]  = {1020,1020,1020,1020,1020,800,800,800};
const int driveB_mode7[]  = {1020,1020,1020,1020,1020,800,800,800};

//######################### MODE 8 ARRAY ############################################//     Random long Pattern
const int driveA_mode8[]  = {200,400,800,800,800,800,400,200,200,400,400,600,600,700,800,1000,1000,1000,1000,900,700,400,200,200,200}; 
const int driveB_mode8[]  = {200,400,800,800,800,800,400,200,200,400,400,600,600,700,800,1000,1000,1000,1000,900,700,400,200,200,200};

//######################### MODE 9 ARRAY ############################################//     Whatever showing different array lengths
const int driveA_mode9[]  = {0,400,500,600,700,800,900,1023};
const int driveB_mode9[]  = {0,400,500,600,700,800,900,1023, 1023, 900, 800, 700, 600, 500, 400, 0};

//######################### MODE 10 ARRAY ###########################################//     Motors opposing sweep - Kinda Cool feeling 
const int driveA_mode10[] = {0,34,68,102,136,170,204,238,272,306,340,374,408,442,476,510,544,578,612,646,680,714,748,782,816,850,884,918,952,986,1020};
const int driveB_mode10[] = {1020,986,952,918,884,850,816,782,748,714,680,646,612,578,544,510,476,442,408,374,340,306,272,238,204,170,236,102,68,34,0};

//######################### MODE xx ARRAY - RampingSweeps1 - elaborated on mode9array###########################################//
//const int driveA_modeXX[] = {0,25,50,75,100,125,150,175,200,225,250,275,300,325,350,375,400,425,450,475,500,525,550,575,600,625,650,675,700,725,750,775,800,825,850,875,900,925,950,975,1000,1023,0,34,68,102,136,170,204,238,272,306,340,374,408,442,476,510,544,578,612,646,680,714,748,782,816,850,884,918,952,986,1020,0,51,102,153,204,255,306,357,408,459,510,561,612,663,714,765,816,867,918,969,1020,0,102,204,306,408,510,612,714,816,918,1020};
//const int driveB_modeXX[] = {1020,995,970,945,920,895,870,845,820,795,770,745,720,695,670,645,620,595,570,545,520,495,470,445,420,395,370,345,320,295,270,245,220,195,170,145,120,95,70,45,20,0,1020,986,952,918,884,850,816,782,748,714,680,646,612,578,544,510,476,442,408,374,340,306,272,238,204,170,136,102,68,34,0,1020,969,918,867,816,765,714,663,612,561,510,459,408,357,306,255,204,153,102,51,0,1020,918,816,714,612,510,408,306,204,102,0};
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

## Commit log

2024-12-09 Minor Updates- 1.2. Added Array Excel Files for example
    [Array_Build1.xlsx, Array_RampingSweeps1_A.csv, Array_RampingSweeps1_B.csv]
2024-12-09 Updated README.md with more instructions. Included 1 page cheatsheet. Added final enclosure stl files.
    [Enclosure4V2_R10 - Back.stl, Enclosure4V2_R10 - Btn_Oval.stl, Enclosure4V2_R10 - Front.stl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]
2024-12-13 R2.0 - No functional/code changes. Added basic device instructions.
2024-12-16 R2.2 - Quick bug fix, 1 motor channel was not working on mode#1-3 in version 2.1. Simple mistake fixed. Found out when I finally built my device.
    [PC4V2_Prog1.ino, pc4v_support.h]
2024-12-17 R2.3 - Clean up Readme instructions, and built in timer-master lib into project file. Realized confusing after working RyanR through setup. No longer need to install timer-master lib. Included in sou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
    [Array_Build1.xlsx, Array_RampingSweeps1_A.csv, Array_RampingSweeps1_B.csv]
